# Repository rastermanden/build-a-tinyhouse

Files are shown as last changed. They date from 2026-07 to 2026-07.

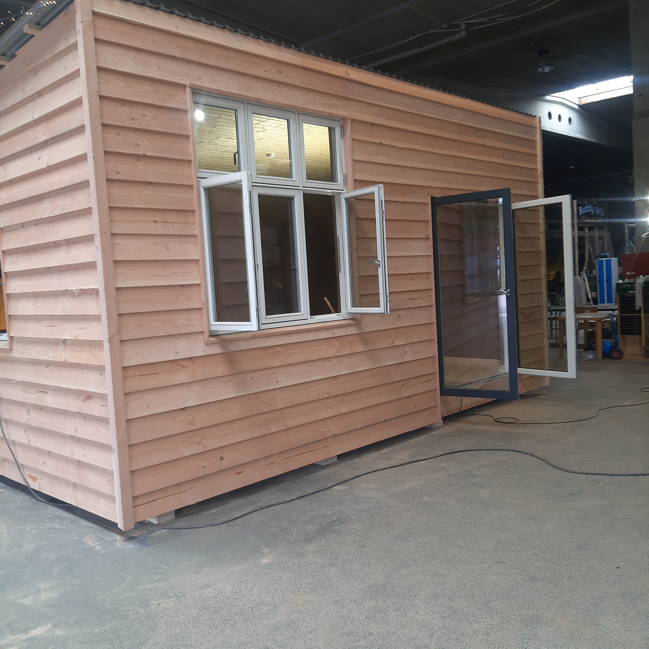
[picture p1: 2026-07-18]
src/assets/steps/vinduer-og-doere/vinduer-monteret-i-vaeg.jpg

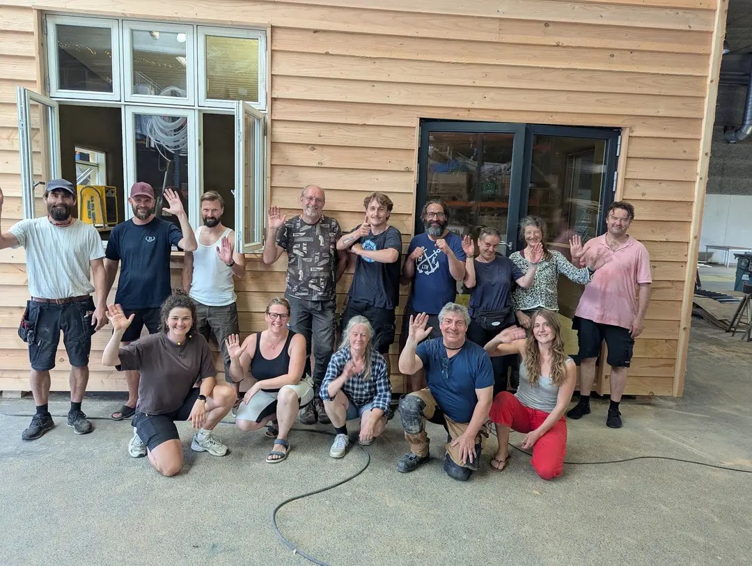
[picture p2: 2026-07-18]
src/assets/hero/tiny-house-hold.jpg

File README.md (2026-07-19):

# 🛖 Byg dit eget tiny house

En åben, trin-for-trin byggeguide til at bygge sit eget tiny house i naturmaterialer –
træ, træfiberisolering og lerpuds. Sitet dokumenterer processen, så andre nemt kan bygge
deres eget.

Bygget med [Astro](https://astro.build/) + [Tailwind CSS](https://tailwindcss.com/).

## 🙏 Stor tak til småBYG & Jonas

Hele metoden, materialevalget og inspirationen kommer fra tiny house-kurset hos
**[småBYG](https://smaabyg.nu/)** ved **Jonas**. Teksterne er skrevet med egne ord, men
bygger helt på deres undervisning og filosofi om at bo småt, billigt og klimavenligt.
Al ære går til dem – tag på kursus, hvis du selv drømmer om et tiny house!

## Kom i gang

```bash
npm install
npm run dev      # udviklingsserver på http://localhost:4321
npm run build    # bygger sitet til dist/
npm run preview  # forhåndsvis produktions-build lokalt
```

## Projektstruktur

```
src/
  content/steps/        # ét byggetrin = én markdown-fil (rækkefølge via "order")
  data/materialelister.json          # prædefinerede mål → fuld materialeliste pr. trin
  data/faktisk-materialeliste.json   # den rigtige indkøbsliste fra fakturaen (konkrete varer)
  assets/steps/<slug>/  # billeder for hvert byggetrin (organiseret i mapper)
  assets/faktisk-materialeliste/  # billeder til den faktiske materialeliste (fx skrueæsker)
  components/           # Header, Footer, Galleri, MaterialTabel, m.fl.
  pages/                # forside, planlægning, beregner, faktisk-materialeliste, om-og-credits, steps/[slug]
public/                 # favicon m.m.
```

### Byggetrin (rækkefølge)

Bundrem → Spær og regler → Gulv → Loft → Vægge og isolering → Vinduer og døre → Tag →
Yderbeklædning → Lerpuds af vægge.

## Sådan tilføjer du billeder

Læg billedfiler i mappen for det pågældende trin, fx:

```
src/assets/steps/bundrem/mit-billede.jpg
```

Understøttede formater: `.jpg`, `.jpeg`, `.png`, `.webp`, `.avif`. Billederne vises
automatisk i galleriet på trinnets side, optimeres ved build, og filnavnet bruges som
alt-tekst. Ingen kodeændring nødvendig.

## Materialelister (statiske lister)

Siden `src/pages/beregner.astro` (rute `/beregner`, vist som **Materialelister**) er ikke en
live-beregner, men viser færdige, statiske lister. Længde/bredde-vælgeren indeholder p.t. kun
den ene færdige størrelse, **600 × 360 cm** (mit faktiske byg), som henviser til den faktiske
liste. Vil du tilføje en ny størrelse, så udvid `laengder`/`bredder` i frontmatter og læg et
objekt under `praedefineredeMaal` i `src/data/materialelister.json` med `laengde_cm`,
`bredde_cm` og en `materialerPrStep` for hvert af de 9 trin (mål i **60 cm**-trin).

> Mængderne i `materialelister.json` er **vejledende estimater** – den faktiske liste
> (600 × 360 cm) er derimod konkrete indkøb fra fakturaen.

## Faktisk materialeliste (fakturaen)

Ud over de vejledende estimater findes en side med den **rigtige indkøbsliste** fra et
konkret byg: `src/pages/faktisk-materialeliste.astro`, der læser
`src/data/faktisk-materialeliste.json`. Fakturaens varer er delt op **pr. byggetrin** i
`materialerPrTrin` (samme trin-nøgler som estimatet), plus en `oevrigt`-liste til varer, der
ikke er trinspecifikke (bits, tape, afgift m.m.). Hver vare har `tekst`, `maengde`, `enhed` og
en `kategori`. Billeder til siden (fx skrueæsker) lægges i `src/assets/faktisk-materialeliste/`.

**Valgt liste på byggetrinnene:** `src/lib/lister.ts` samler de tilgængelige lister ét sted.
Man vælger en liste på Materialeliste-siden (gemmes i `localStorage` under nøglen
`valgtMaterialeliste`), og hvert byggetrin viser derefter et banner med den valgte liste og
netop det trins materialer. Er der ikke aktivt valgt en liste, bruges **den første liste som
standard**, så trinnet altid viser materialer. Man kan skifte mellem lister (der findes p.t.
kun én, men flere kan tilføjes ved at udvide `lister` i `lister.ts`).

Hvert byggetrin viser **kun** materialer, når trinnet er markeret som klar med
`materialerKlar: true` i frontmatter; ellers står der **"Kommer senere"**. Sæt flaget, når du
har opdateret trinnets `materialerPrTrin` i `faktisk-materialeliste.json` med faktiske tal. Der
er ikke længere en separat, generisk materialetabel på trinnene – den valgte liste er kilden.

## Sådan redigerer du et byggetrin

Rediger den tilsvarende markdown-fil i `src/content/steps/`. Frontmatter styrer titel,
resumé, værktøjsliste og `materialerKlar`-flaget; brødteksten skrives i markdown.

## Hosting: GitHub Pages + PR-preview

Sitet udgives til `gh-pages`-branchen:

- **Produktion** (`.github/workflows/deploy.yml`): bygges ved push til `main` og lægges i
  roden af `gh-pages` → `https://rastermanden.github.io/build-a-tinyhouse/`.
- **PR-preview** (`.github/workflows/pr-preview.yml`): hver pull request bygges til
  `pr-preview/pr-<nr>/` og der kommenteres et preview-link på PR'en (via
  [`rossjrw/pr-preview-action`](https://github.com/rossjrw/pr-preview-action)). Previewet
  fjernes automatisk, når PR'en lukkes.

### Engangsopsætning (repo-ejer)

Under **Settings → Pages** skal *Source* sættes til **Deploy from a branch** og branchen
til **`gh-pages`** (mappe `/ (root)`). Herefter kører det automatisk.

## Tegninger i FreeCAD

Vil du lave dine egne konstruktionstegninger, ligger der en kort guide i
[`docs/freecad-parametrisk-konstruktion.md`](docs/freecad-parametrisk-konstruktion.md).
Den viser, hvordan du bygger træskelettet parametrisk i FreeCAD med vores dimensioner
(45×95 og 45×120 mm, 60 cm-modul), så du kan ændre husets længde/bredde ét sted og få både
3D-model og tegninger til at følge med. Med links til de relevante FreeCAD-workbenches.

## Ansvarsfraskrivelse

Dette er et personligt hobbyprojekt og er ikke officielt tilknyttet småBYG. Materialemængder
og mål er vejledende. Følg altid gældende regler og vejledninger, og tjek selv efter.

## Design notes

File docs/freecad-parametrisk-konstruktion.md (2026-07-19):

# Parametriske konstruktionstegninger i FreeCAD

En kort guide til at tegne tiny house-skelettet i [FreeCAD](https://www.freecad.org/) med
**vores dimensioner af konstruktionstræ**, sådan at du kan ændre husets længde og bredde
bagefter og få både 3D-model og tegninger til at følge med.

> Skrevet til **FreeCAD 1.0** eller nyere. Hent den nyeste version –
> den er markant bedre til byggekonstruktion end de gamle 0.x-udgaver.
> Download: <https://www.freecad.org/downloads.php>

## Vores dimensioner

Hele huset bygges op omkring et **modul på 60 cm**. De bærende trædimensioner er:

| Element | Dimension |
|---|---|
| Bundrem, vægregler, top-/bundskinne | 45 × 95 mm |
| Tagspær | 45 × 120 mm |
| Modul (c/c mellem regler og spær) | 600 mm |
| Reference-størrelse | 600 × 360 cm |

## Hvilke workbenches

Du skal bruge to – én til at bygge modellen, én til at lave tegningerne:

| Formål | Workbench | Dokumentation |
|---|---|---|
| Modellere træskelettet i 3D | **BIM** (hed tidligere *Arch*) | <https://wiki.freecad.org/BIM_Workbench> |
| Lave 2D-tegninger (plan, snit, opstalt, mål) | **TechDraw** | <https://wiki.freecad.org/TechDraw_Workbench> |
| Styre alle mål fra ét sted | **Spreadsheet** | <https://wiki.freecad.org/Spreadsheet_Workbench> |
| 60 cm-grid og kopiering af regler/spær | **Draft** | <https://wiki.freecad.org/Draft_Workbench> |

Alle fire følger med i standard-FreeCAD – ingen tilføjelser nødvendige.

## Sådan gør du det parametrisk

Målet: skift **ét tal**, og hele huset skalerer. Nøglen er **Spreadsheet + udtryk**.
Det skal planlægges *fra begyndelsen* – det er svært at eftermontere.

### 1. Lav et regneark med de styrende mål

Åbn **Spreadsheet**-workbenchen, opret et regneark og skriv dine parametre ind. Giv hver
celle et **alias** (højreklik på cellen → *Alias*), så du kan referere til den:

| Celle | Værdi | Alias |
|---|---|---|
| B1 | 6000 | `laengde` |
| B2 | 3600 | `bredde` |
| B3 | 600 | `modul` |
| B4 | 45 | `regel_b` |
| B5 | 95 | `regel_h` |
| B6 | 120 | `spaer_h` |

Læg gerne en udregnet celle ind for antal regler:

| Celle | Formel | Alias |
|---|---|---|
| B7 | `=laengde / modul + 1` | `antal_regler` |

> **Hold dig til hele moduler.** `laengde` og `bredde` bør altid være et multiplum af 600,
> så konstruktionen går op i 60 cm-rasteret ligesom det færdige byg.

### 2. Byg med udtryk i stedet for tal

Når du opretter en bjælke (BIM → *Structure*/*Beam*), så klik på det lille **f(x)-ikon**
i mål-feltet og skriv et **udtryk** i stedet for et fast tal:

- Bundremmens længde: `Spreadsheet.laengde`
- Bjælkeprofil: bredde `Spreadsheet.regel_b`, højde `Spreadsheet.regel_h`
- Spærhøjde: `Spreadsheet.spaer_h`

Nu er bjælken bundet til regnearket. Ændrer du `laengde`, følger bjælken med efter et
**recompute** (F5 / det blå genberegn-ikon).

Læs mere om udtrykssproget: <https://wiki.freecad.org/Expressions>

### 3. Lad antallet af regler skalere med

En enkelt bjælke strækker sig fint, men "der skal komme en ekstra stolpe når huset bliver
længere" kræver et **array**. Marker én regel og lav et **Draft Ortho Array**, hvor du
sætter *antallet* som et udtryk:

- Antal (X): `Spreadsheet.antal_regler`
- Interval (X): `Spreadsheet.modul`

Så popper der automatisk en ny regel op, hver gang du krydser et 60 cm-modul. Samme princip
for spærene.

Draft Array: <https://wiki.freecad.org/Draft_OrthoArray>

### 4. Definér profilerne én gang

Tegn 45 × 95- og 45 × 120-profilerne som **Sketcher**-rektangler (eller brug BIM' indbyggede
profil-bibliotek) og genbrug dem. Ændrer du profilet, opdaterer alle bjælker der bruger det.

Sketcher: <https://wiki.freecad.org/Sketcher_Workbench>

## Fra model til tegning

Når skelettet står, laver du tegningerne i **TechDraw**:

1. Opret et tegningsblad (*Insert Default Page*).
2. Vælg modellen og indsæt en **view** i den ønskede retning – plan (ovenfra), facade, og et
   **tværsnit** gennem væggen så man ser regler og isolering.
3. Tilføj **målsætning** og en titelblok.
4. Eksportér til **PDF** eller **SVG**.

Det bedste: **tegningerne er koblet til modellen.** Ændrer du huset fra 600 til 660 cm i
regnearket, opdaterer både 3D-modellen *og* alle tegninger med nye mål på ét recompute.

## Til illustrationer på sitet

Ud over de tekniske tegninger:

- **Isometrisk skærmbillede:** drej 3D-viewet til en let isometrisk vinkel og tag et
  screenshot – godt til "sådan ser skelettet ud"-billeder.
- **Farvede snit:** BIM' **Section Plane** laver gennemskårne snit, hvor lagene (træ,
  træfiberisolering, lerpuds) ses tydeligt – oplagt til en byggeguide.
- **Render (fotorealistisk):** *Render Workbench* installeres via Addon Manager. Overkill til
  konstruktion, men fint til det færdige hus.

## Realistisk forventning

| Ambitionsniveau | Indsats |
|---|---|
| Ændre en enkelt bjælkes mål | Gratis, virker altid |
| Ét regneark styrer alle **mål** (bjælker strækker sig) | Moderat – kræver udtryk fra start |
| Ét regneark styrer også **antal** regler/spær (arrays) | Mere arbejde, men fuldt muligt |
| Ændre størrelse på et *færdigbygget* projekt bagefter | Svært – planlæg det fra begyndelsen |

## Lad Claude bygge modellen (MCP-server)

Vil du ikke klikke det hele manuelt, findes der **MCP-servere til FreeCAD**, der lader Claude
styre FreeCAD direkte: oprette/ændre objekter, køre Python-kode inde i FreeCAD og tage
skærmbilleder af 3D-viewet, så Claude kan se modellen og rette til undervejs. Det passer godt
til den parametriske tilgang her, fordi hele setuppet (Spreadsheet, aliaser, udtryk,
Draft-arrays) kan skrives via FreeCADs Python-API.

**Anbefaling:** [`neka-nat/freecad-mcp`](https://github.com/neka-nat/freecad-mcp) – den mest
modne (understøtter FreeCAD 1.0/1.1, har skærmbillede-feedback, kører med **Claude Desktop**).
Vil du hellere bruge **Claude Code** i terminalen, så tag
[`contextform/freecad-mcp`](https://github.com/contextform/freecad-mcp) i stedet.

| Din situation | Vælg |
|---|---|
| Standard (Claude Desktop-appen) | `neka-nat/freecad-mcp` |
| Vil bruge Claude Code i terminalen | `contextform/freecad-mcp` |

Sådan kommer du i gang:

1. Installér serveren (kopiér addon'et til FreeCADs `Mod`-mappe og konfigurér Claude – se
   serverens README).
2. Giv Claude **denne guide** som kontekst, så den kender vores dimensioner (45×95, 45×120)
   og 60 cm-modulet.
3. Bed den bygge det parametriske skelet – f.eks. *"opret et Spreadsheet med laengde/bredde/
   modul som aliaser og byg bundrem + regler c/c 600 med udtryk"*.

> **Bemærk:** Det er et **superviseret** værktøj, ikke en autopilot. Det får hurtigt 80 % op
> at stå, men tjek altid mål og placeringer efter – konstruktionstegninger skal være
> korrekte. Serveren kører **lokalt** på din egen maskine (FreeCAD + Claude side om side).

## Nyttige links

- FreeCAD – download: <https://www.freecad.org/downloads.php>
- BIM Workbench (byg skelettet): <https://wiki.freecad.org/BIM_Workbench>
- TechDraw Workbench (lav tegninger): <https://wiki.freecad.org/TechDraw_Workbench>
- Spreadsheet Workbench (styrende mål): <https://wiki.freecad.org/Spreadsheet_Workbench>
- Expressions (udtrykssproget): <https://wiki.freecad.org/Expressions>
- Draft Array (kopier regler/spær): <https://wiki.freecad.org/Draft_OrthoArray>
- Al FreeCAD-dokumentation: <https://wiki.freecad.org/>
- MCP-server (Claude Desktop): <https://github.com/neka-nat/freecad-mcp>
- MCP-server (Claude Code): <https://github.com/contextform/freecad-mcp>
- FreeCAD-forummet (spørg om hjælp): <https://forum.freecad.org/>

---

> Del af den åbne byggeguide. Mål og fremgangsmåde er vejledende – tjek altid selv efter og
> følg gældende regler.

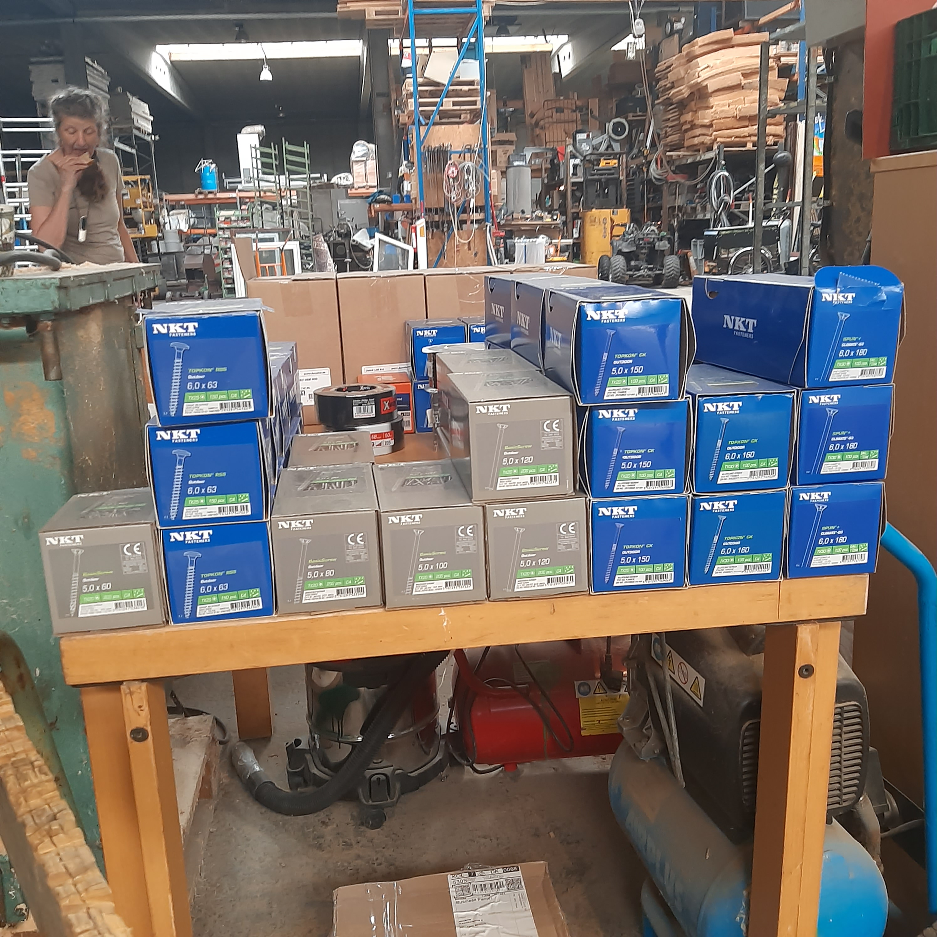
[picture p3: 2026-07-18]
src/assets/faktisk-materialeliste/nkt-skrueaesker-topkon-og-basic.jpg

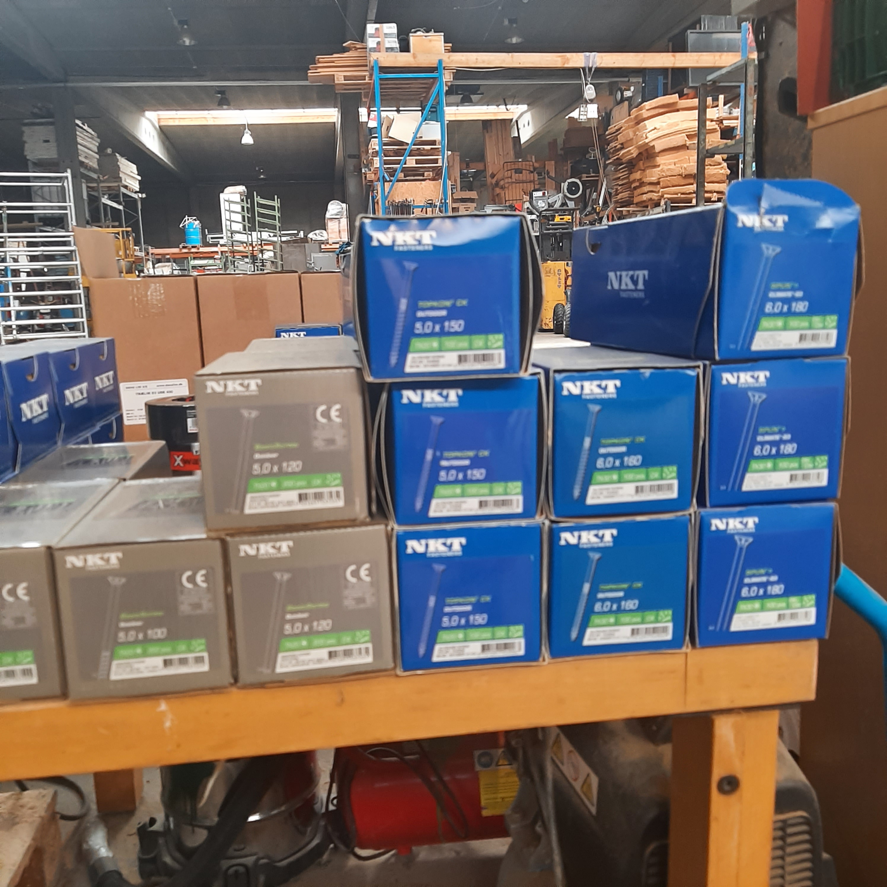
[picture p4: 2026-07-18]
src/assets/faktisk-materialeliste/nkt-skrueaesker-paa-hylde.jpg

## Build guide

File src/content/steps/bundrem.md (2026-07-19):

---
order: 1
titel: Bundrem
resume: Fundamentet for hele huset. En stiv, retvinklet ramme i træ, der bærer gulv, vægge og tag.
beregnerNoegle: bundrem
tid: 1-2 dage
materialerKlar: true
vaerktoj:
  - Akku-boremaskine og slagskruemaskine
  - Håndrundsav eller kap-/geringssav
  - Vinkel og lang lige lægte til kontrol af diagonaler
  - Vaterpas (langt) og tommestok/målebånd
  - Skruetvinger
  - Blyant og kridtsnor
materialer:
  - navn: Konstruktionstræ til rammen
    dimension: 45×95 mm
    note: Den bærende ramme og strøer (moduldelt pr. 60 cm)
  - navn: Skruer til konstruktion
    dimension: 5×90-100 mm
    note: Rustfrie eller varmforzinkede
  - navn: Fugtspærre / underlagspap
    note: Mellem trailer/sokkel og træ, så træet ikke suger fugt
  - navn: Vinkelbeslag
    note: Til at holde ramme og tværregler i vinkel
---

Bundremmen er selve grundlaget for dit tiny house. Det er den ramme, der bærer gulvet,
væggene og i sidste ende taget – så her betaler det sig at være grundig. Bliver bundremmen
skæv eller vrid, følger resten af huset med.

Hele huset bygges op omkring et **modul på 60 cm**. Det gør indkøb, isolering og
pladematerialer nemt, fordi alt går op i standardmål. Bundremmen sætter dette raster fra
begyndelsen.

## Sådan gør du

1. **Læg fugtspærre** dér, hvor træet møder trailer, sokkel eller punktfundament. Træ må
   aldrig stå og suge fugt.
2. **Byg den ydre ramme** af kraftigt konstruktionstræ på højkant, og skru den sammen i
   hjørnerne. Til de gennemgående samlinger af bundramme, spær og strø bruges **ekstra
   lange konstruktionsskruer** (fx NKT Ø8 mm i 240 og 280 mm), så der er godt bid i træet.
3. **Kontrollér vinklen** ved at måle begge diagonaler – de skal være lige lange. Juster
   til rammen er helt retvinklet.
4. **Sæt strø** ind pr. 60 cm (center/center). Strøerne er de tværgående bjælker, der bærer
   gulvet og fastholder modulet – skru dem fast gennem rammen med de lange skruer.
5. **Fastgør rammen** til underlaget, så huset ikke kan flytte sig.

## Gode råd

- Brug tid på at få bundremmen **helt plan og i vinkel** – det sparer dig for besvær i
  alle de følgende trin.
- Mål altid diagonalerne igen, når du har skruet fast. Træ kan bevæge sig undervejs.

> Denne fremgangsmåde bygger på det, jeg lærte på tiny house-kurset hos **småBYG** ved
> **Jonas**. Se [smaabyg.nu](https://smaabyg.nu/) for kurser og mere inspiration.

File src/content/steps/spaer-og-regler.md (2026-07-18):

---
order: 2
titel: Spær og regler
resume: Husets skelet. Lodrette regler og tagspær sætter formen og bærer isolering, beklædning og tag.
beregnerNoegle: spaer-og-regler
tid: 2-4 dage
vaerktoj:
  - Kap-/geringssav
  - Akku-boremaskine og slagskruemaskine
  - Vaterpas og lodret snor/laser
  - Skruetvinger og vinkelbeslag
  - Målebånd og blyant
materialer:
  - navn: Regler til vægge (stolper)
    dimension: 45×95 mm
    note: Placeres pr. 60 cm, så isolering og plader passer
  - navn: Top- og bundskinne
    dimension: 45×95 mm
    note: Binder reglerne sammen foroven og forneden
  - navn: Spær til tag
    dimension: 45×120 mm
    note: Dimension afhænger af spændvidde og snelast
  - navn: Vinkelbeslag og spærbeslag
    note: Til samlinger mellem regler, skinner og spær
  - navn: Konstruktionsskruer
    dimension: 5×90-100 mm
---

Når bundremmen står, rejser du husets skelet. **Reglerne** er de lodrette stolper i
væggene, og **spærene** danner tagets form. Tilsammen bestemmer de husets højde, hældning
og hvor stærkt det står.

Ligesom bundremmen følger skelettet **60 cm-modulet**. Reglerne står med 60 cm mellem
centrene, så træfiberisolering og plader senere passer uden alt for meget tilskæring.

## Sådan gør du

1. **Byg vægrammerne** liggende på et plant underlag: bund- og topskinne med regler pr.
   60 cm imellem.
2. **Rejs væggene** én ad gangen, lod dem op, og afstiv dem midlertidigt med skråstivere.
3. **Bind væggene sammen** i hjørnerne, og kontrollér at alt er i lod og vinkel.
4. **Rejs spærene** oven på væggene i den ønskede taghældning, og fastgør dem med
   spærbeslag.
5. **Afstiv skelettet**, så det står stift, indtil beklædningen låser det fast.

## Gode råd

- Byg vægelementer på jorden, hvor du kan arbejde præcist – det er langt nemmere end at
  bygge lodret.
- Hold styr på modulet hele vejen: 60 cm mellem centrene gør alle de næste trin lettere.

> Metode og opbygning er inspireret af **småBYG** og **Jonas**. Tusind tak for et fantastisk
> kursus – se mere på [smaabyg.nu](https://smaabyg.nu/).

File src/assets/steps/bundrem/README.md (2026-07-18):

# Billeder: bundrem

Læg billeder til dette byggestep i denne mappe.

- Understøttede formater: **.jpg / .jpeg / .png / .webp / .avif**
- Filnavnet bruges som alt-tekst (fx `bundrem-i-vinkel.jpg` → "bundrem i vinkel").
- Billederne vises automatisk i galleriet på step-siden og optimeres ved build.

Ingen kodeændring nødvendig – bare læg filerne her.

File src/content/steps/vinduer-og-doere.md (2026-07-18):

---
order: 6
titel: Vinduer og døre
resume: Lys og adgang. Vinduer og døre monteres tæt i klimaskærmen, så der hverken trækker eller siver fugt ind.
beregnerNoegle: vinduer-og-doere
tid: 1-3 dage
vaerktoj:
  - Akku-boremaskine og slagskruemaskine
  - Vaterpas og kiler
  - Fugepistol
  - Hobbykniv og tape til tætning
  - Målebånd og blyant
materialer:
  - navn: Vinduer
    note: Færdige elementer – gerne genbrug, hvis målene passer
  - navn: Dør(e)
    note: Yderdør i god kvalitet
  - navn: Fugebånd / komprimeringsbånd
    note: Tætner mellem karm og konstruktion
  - navn: Tætningstape
    note: Binder dampbremse og vindspærre sammen om åbningen
  - navn: Kiler og monteringsskruer
  - navn: Lister til inddækning
---

Vinduer og døre giver lys, luft og adgang – og de er dér, hvor mange huse taber varme og
bliver utætte. Derfor handler dette trin lige så meget om **tætning** som om selve
monteringen.

Billedet på denne side er fra mit eget byggeri: vinduerne prøvemonteret i væggen, før den
endelige inddækning. Netop her er det vigtigt at få karm og klimaskærm til at spille
sammen.

## Sådan gør du

1. **Forbered åbningerne** i vægrammen, så de passer til vinduernes og dørens karmmål (husk
   plads til kiler og fuge).
2. **Sæt elementet i**, kil det op, og kontrollér at det står i lod, vater og plan.
3. **Fastgør karmen** med monteringsskruer gennem kilerne.
4. **Tætn hele vejen rundt**: komprimeringsbånd udvendigt, og tape der binder vindspærre og
   dampbremse sammen med karmen.
5. **Monter lister/inddækning** til sidst, både ude og inde.

## Gode råd

- Genbrugsvinduer er både billige og bæredygtige – planlæg gerne husets mål efter de
  vinduer, du kan skaffe.
- Brug god tid på tætningen. Et utæt vindue mærkes resten af husets levetid.

> Tilgangen til tætte samlinger og genbrug er inspireret af **småBYG** og **Jonas**.
> Se [smaabyg.nu](https://smaabyg.nu/).

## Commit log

2026-07-18 Byg tiny house-dokumentationssite med Astro + Tailwind
    Nyt statisk site der dokumenterer processen med at bygge et tiny house i
    naturmaterialer, trin for trin, inspireret af og med stor tak til småBYG og Jonas.
    - 9 byggetrin (bundrem → lerpuds) som content collection, hvert med sektioner
    for materialer, værktøj og billeder + forrige/næste-navigation
    - Materialeberegner: vælg længde/bredde (60 cm-modul, max 600×360 cm) og få den
    fulde, prædefinerede materialeliste fra materialelister.json (opslag pr. mål)
    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
2026-07-18 Tilføj faktisk materialeliste fra fakturaen med skrueæske-billeder
    Ny side der viser den rigtige indkøbsliste fra et konkret byg – konkrete
    varer, varenumre og mængder renskrevet fra tømmerhandlens faktura,
    grupperet i kategorier. Inkluderer billeder af de leverede NKT-skrueæsker.
    Claude-Session: https://claude.ai/code/session_01Y9vYzjKHkB3xoiJYc8jy5S
2026-07-18 Knyt faktisk materialeliste til husmål 600×360 cm
    Angiv husets størrelse (600 × 360 cm, 21,6 m²) på siden, så det er
    tydeligt, hvilke mål de konkrete mængder svarer til.
    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
2026-07-18 Henvis fra beregneren til faktisk liste ved 600×360 cm
    Når man vælger netop det mål, den faktiske indkøbsliste dækker (600×360 cm),
    viser beregneren nu et kald-ud med link til den faktiske materialeliste –
    både i "ingen færdig liste"-tilfældet og hvis målet senere får en færdig liste.
    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
2026-07-18 Fjern varenummer-kolonne fra faktisk materialeliste
    Listen viser nu kun vare og antal – varenumrene er fjernet fra visningen
    for et renere overblik.
    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
2026-07-18 Vis positiv henvisning ved 600×360 i stedet for "ingen liste"
    Vælger man netop det mål, den faktiske indkøbsliste dækker, viste
    beregneren både "Ingen færdig materialeliste ... endnu" og et link til
    den faktiske liste – selvmodsigende. Nu erstattes tom-tilstanden af en
    positiv henvisning direkte til den faktiske liste.
    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
2026-07-18 Forenkl overblik på faktisk materialeliste
    Fjern boksene Leveret, Varelinjer og Kategorier fra overblikket – kun
    husmålet vises nu. Ryd ubrugt beregning op.
    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
2026-07-18 Tilføj tilbudsforespørgsel til leverandører via e-mail
    Ny sektion på faktisk materialeliste, der genererer en færdig
    tilbuds-e-mail med hele listen og åbner den i brugerens mailprogram
    (mailto). Brugeren kan sætte flere leverandører i cc og få vejledning i
    at konkurrenceudsætte ordren for at opnå rabat. Inkluderer også
    "kopiér e-mailtekst" som fallback.
    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
2026-07-18 Reframe beregner som statiske materialelister med kun 600×360
    Siden er ikke en live-beregner, men færdige, statiske lister. Længde/
    bredde-vælgeren indeholder nu kun den ene tilgængelige størrelse
    (600×360 cm) og forvælges + vises automatisk. Al synlig "beregner"-
    ordlyd er ændret til "materialelister" på tværs af siderne.
    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
2026-07-18 Saml materiale-menupunkter til ét
    Fjern det overlappende "Materialelister"-menupunkt (var reelt en tragt til
    den faktiske liste) og behold ét punkt, "Materialeliste", der peger på den
    faktiske liste. Beregner-siden er stadig tilgængelig via links på siderne.
    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
2026-07-18 Gør savværks-bestilling nemmere at finde
    Tilføj et tydeligt link fra Materialeliste-siden direkte ned til
    savværks-bestillingssektionen på yderbeklædning-trinnet (via anker
    #bestil-savvaerk), så den er let at finde uden et ekstra menupunkt.
    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
2026-07-20 Tilføj parametrisk FreeCAD-model af tiny house-skelettet
    Bygger hele skelettet fra et regneark, så husets mål kan ændres ét sted
    og resten følger med. Verificeret ved at køre 6000x3600 -> 7200x4800
    igennem: regelantal og placeringer opdaterer korrekt.
    Konstruktion:
    - Bundrem på højkant, 195 mm. Front/bag er to 45 mm lægter limet sammen
    (tegnet som separate emner, så limfugen ses og hver lægte kan tælles).
    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
    [tinyhouse_skelet.FCStd]
2026-07-20 Tilføj taghældning med udhugget spærsæde
    Forvæg 3150 mm, bagvæg 2850 mm, begge målt som overkant regel over
    terræn. Det giver 300 mm fald over husets bredde, altså 8,33 % og en
    spærvinkel på 4,764 grader.
    Spærene får et vandret udhugget sæde i begge ender, så de hviler plant
    på topskinnerne i stedet for at røre dem i en kant. Sædet er 142 mm
    langt og hugget 30 mm dybt ved yderkanten. Gavlreglerne skæres af i
    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
    [tinyhouse_skelet.FCStd]
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2026-07-20 Byg mange huse i stedet for ét
    Modellen kunne kun bygge 6000 x 3600. Alt var bundet til regnearket med
    udtryk, så geometrien kunne allerede følge med - det der manglede var
    rammen om den.
    skelet.py byg(navn, **afvigelser) -> dokument
    huse.py listen over huse
    tegninger.py tegn(doc, udmappe, titel)
    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
    [tinyhouse_skelet.FCStd]
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2026-07-20 Farv emnerne efter tværsnit i stedet for rolle
    Farven blev valgt ud fra emnets navn: hvert byggetrin sin tone, plus en
    lys/mørk variation på de to-delte samlinger. Det sagde noget om hvor
    emnet sad, men ingenting om hvad det var savet af.
    Nu bestemmer tværsnittet farven. Emner af samme dimension står i samme
    farve uanset hvor de sidder, så man kan se på modellen hvilket træ der
    skal bestilles, og hvad der kan saves af det samme stykke:
    45 x 195 7 emner bundrem (6) + strø
    45 x 145 14 emner regler (8) + hjørnestolper (4) + topskinner (2)
    45 x 120 3 emner spær
    Strøet får dermed samme farve som bundremmen, og topskinnerne samme som
    reglerne.
    Prisen er at de to-d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
2026-11-08 Ret trædimensioner i docs, trin og materialelister til FreeCAD-modellen
    Modellen i freecad/skelet.py bruger regel_h=145, spaer_h=195 og bundrem_h=195
    (bundrem front/bag = to 45×195 lag = 90×195). Docs, README, trin-sider,
    planlægningssiden og materialelisterne sagde 45×95 og 45×120.
    - docs/freecad-parametrisk-konstruktion.md: emneopdelt dimensionstabel,
    regel_h 145 / spaer_h 195 i regnearkstabellen, profiler og MCP-kontekst
    - README.md: FreeCAD-afsnittet
    - bundrem.md: 90×195 mm (to 45×195 lag), strø 45×195 mm
    - spaer-og-regler.md: regler 45×145, topskinne 45×145 (ingen bundskinne),
    spær 45×195, og vægrammerne beskrives uden bundskinne
    - vaegge-og-isolering.md: isolering 1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
